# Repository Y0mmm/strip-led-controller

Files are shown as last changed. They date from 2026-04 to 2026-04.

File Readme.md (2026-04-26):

# STM8 RGB LED Strip Controller (Infrared NEC)

Custom low-cost RGB LED strip controller based on STM8, featuring Infrared (NEC protocol) control and perceptually-correct dimming.

## Overview

I bought a Paulmann SimpLED RGB strip to use as a bedside lamp. However, I was not satisfied with its functionalities (RGB light strobes before sleep didn’t make much sense), the colors were too aggressive for my eyes, and the dimming was linear (whereas human vision behaves more like a logarithmic response).

I initially wanted to reflash the original controller, but there were no markings on the IC package. So I decided to rebuild it from scratch.

This redesign addresses those issues with:
- Smooth, perceptually-correct brightness control
- Customizable color profiles
- Infrared remote compatibility (NEC protocol)
- Minimal, low-cost hardware

### Features

- Customizable color mapping
- Smooth, perceptually-correct brightness control
- Customizable color functions (ie: go-to-bed that slowly switch off the lights)
- Drop-in replacement PCB for original enclosure

## Hardware
### PCB Design
The PCB form factor and the position of the power barrel connector are designed to fit into the original controller enclosure and to be powered with the original 12VDC power supply.
I chose to use an STM8S001, as it is inexpensive, low-power, and more than sufficient for this project.

PCB design files are available in the PCB/ directory (KiCad).

### Preview
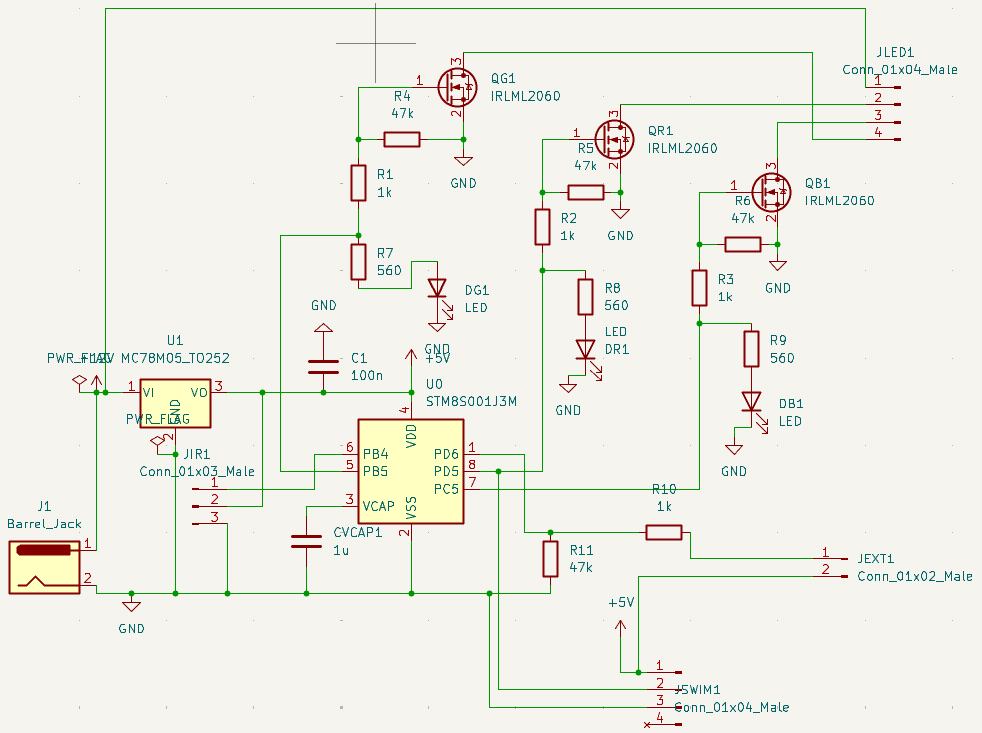
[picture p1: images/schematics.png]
wireing schematics


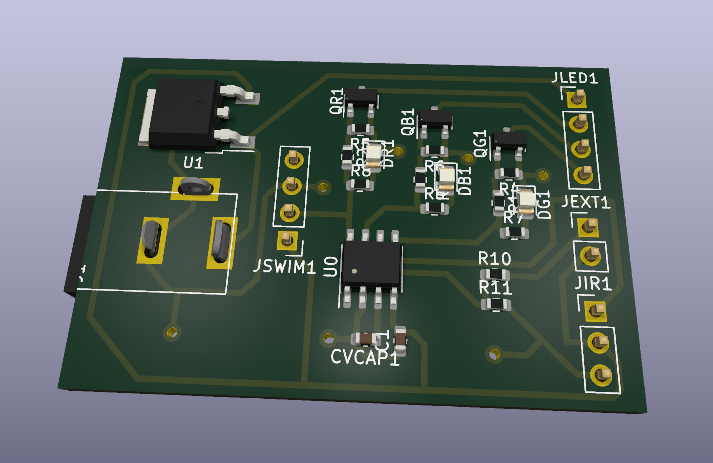
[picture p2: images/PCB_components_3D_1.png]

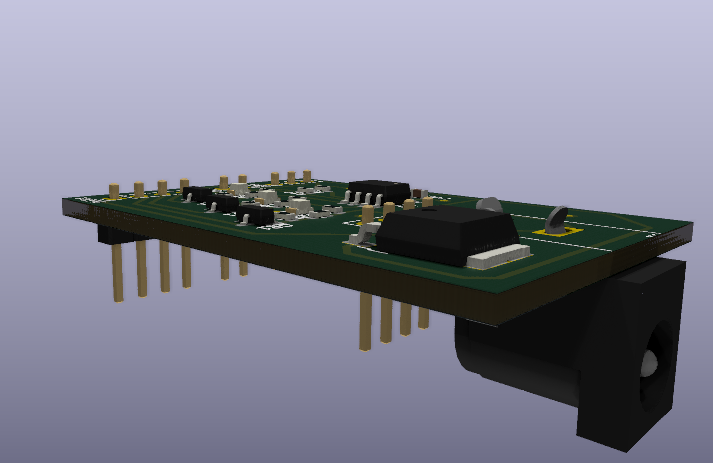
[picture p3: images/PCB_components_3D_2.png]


### Materials
|Name | Value | 	Number	| Comments|
| --- | ----- | --- | ---|
|STM8S001J3M3 |	|	1	|https://fr.farnell.com/stmicroelectronics/stm8s001j3m3/mcu-8bit-16mhz-nsoic-8/dp/4036166|
|MC78M05CDTRKG| | 		1|	7805 LDO regulator https://fr.farnell.com/on-semiconductor/mc78m05cdtrkg/regulateur-de-tension/dp/1703354|
|IRLML6344TRPBF	||	3	|N-channel MOSFETs used to control the LEDs https://fr.farnell.com/infineon/irlml6344trpbf/mosfet-canal-n-30v-6-3a-sot23/dp/1857299|
|MJ-179PH|	|	1|	Barrel power connector https://fr.farnell.com/multicomp-pro/mj-179ph/embase-basse-tension-12vdc-4a/dp/1737246|
|TSOP18438	|	|1|	IR receiver (replacement for the original one I broke — this one is actually more powerful) https://fr.farnell.com/vishay/tsop18438/recepteur-ir-24m-0-12mw-m2-lateral/dp/2889952|
|C1|	100 nF	|1|	1608 SMD|
|CVCAP	|1 µF	|1|	1608 SMD|
|R1, R2, R3	|1 kΩ|	3	|Load resistors for the MOSFETs, 1608 SMD|
|R4, R5, R6	|47 kΩ|	3	|Pull-down resistors, 1608 SMD|
|R7, R8, R9	|550 Ω|	3	|Optional load resistors for the LEDs, 1608 SMD|
|R10|	47 kΩ|	1	|Optional pull-down resistor for the JEXT button (not implemented)|
|R11|	1 kΩ	|1|	Load resistor for the optional JEXT button|
|RGB LEDs|	R, G, B|	3|	Optional, for debugging without the LED strip connected, 2012 SMD|
|Pin headers	|	|4	|Used for SWIM programming, IR receiver connection, and LED strip connection|

### IR remote buttons mapping : 
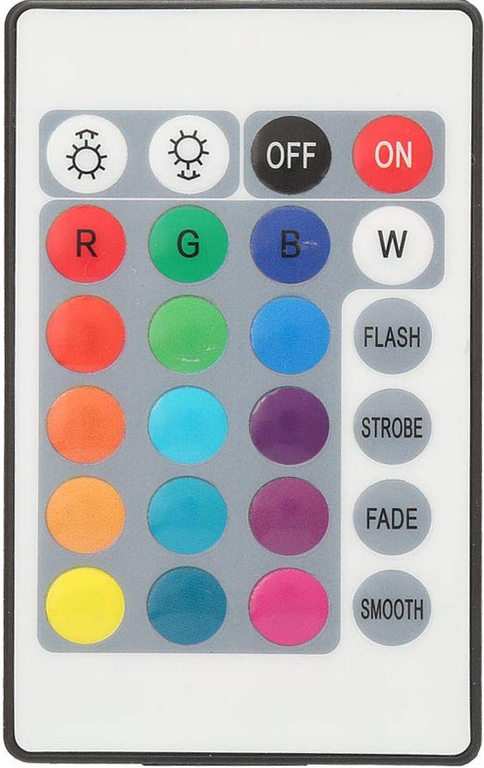
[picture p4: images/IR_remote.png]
IR Remote


For all the buttons, the NEC Address is `0xef00`. The commands are the following:
| Col A  | Col B  | Col C  | Col D  |
| --- | --- | --- | --- |
| `0x00` | `0x01` | `0x02` | `0x03` |
| `0x04` | `0x05` | `0x06` | `0x07` |
| `0x08` | `0x09` | `0x0a` | `0x0b` | 
| `0x0c` | `0x0d` | `0x0e` | `0x0f` | 
| `0x10` | `0x11` | `0x12` | `0x13` | 
| `0x14` | `0x15` | `0x16` | `0x17` | 

## Firmware
I wrote the NEC infrared decoder from scratch, mainly for fun. It is built around a finite state machine. The command handler is implemented as a large switch statement.

The firmware is interrupt-driven, aiming to minimize power consumption (although it is not battery-powered).

You can add your own colors in src/config/led_config.c, adjust command codes to match your remote control, and implement additional features.

Since the STM8S001 does not include an FPU, all arithmetic is done using fixed-point math.

I used OpenAI Codex at the end to help refactor parts of the code.

### TODO
Implement features using a button connected to JEXT (e.g., on/off)

### Compile
I use SDCC for compilation. 
usage :
`make clean && make`

flash: I used a stlinkv2 with a SWIM Connector
`make flash`

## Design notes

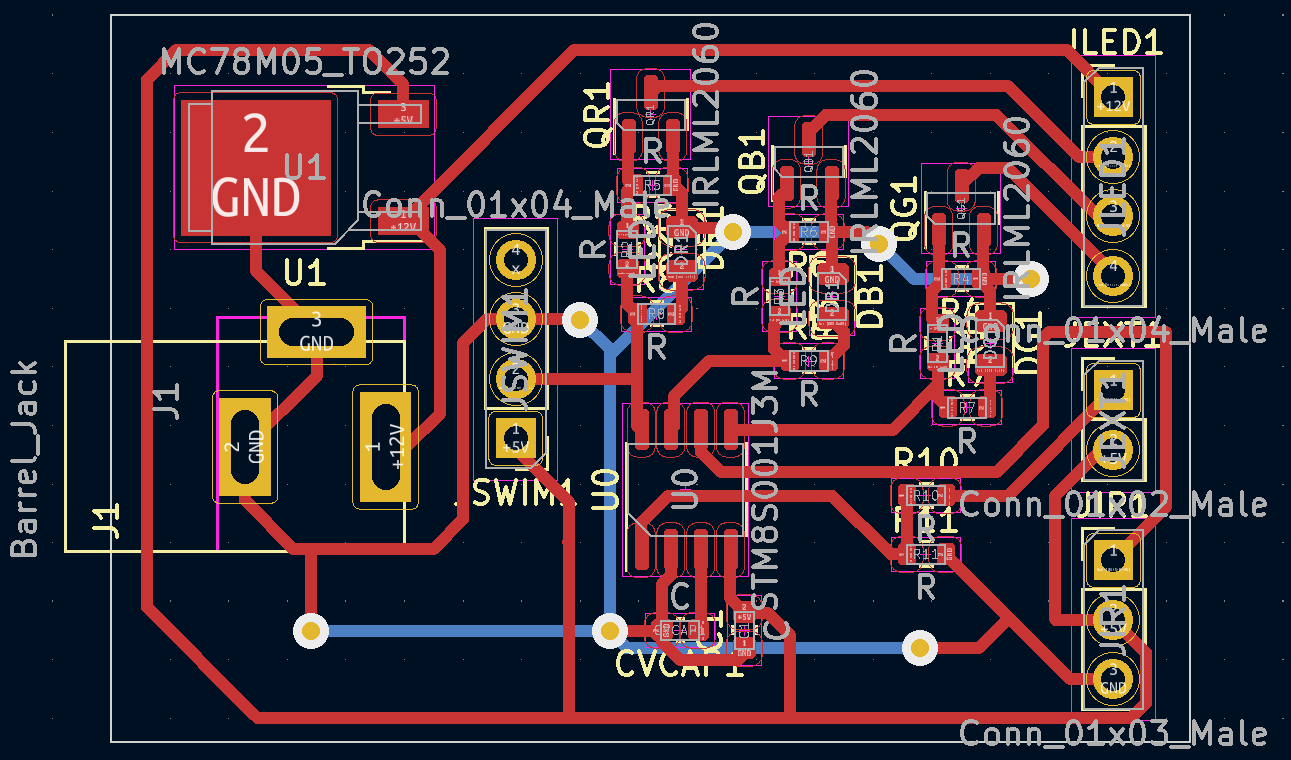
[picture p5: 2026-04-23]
images/PCB_schematics.png

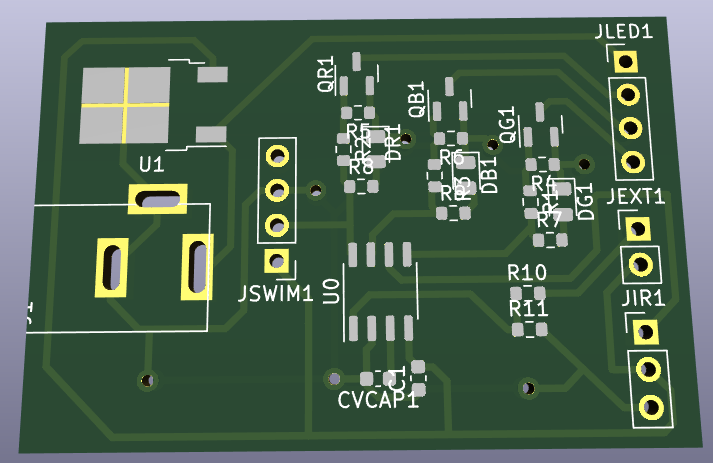
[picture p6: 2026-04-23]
images/PCB_3D.png

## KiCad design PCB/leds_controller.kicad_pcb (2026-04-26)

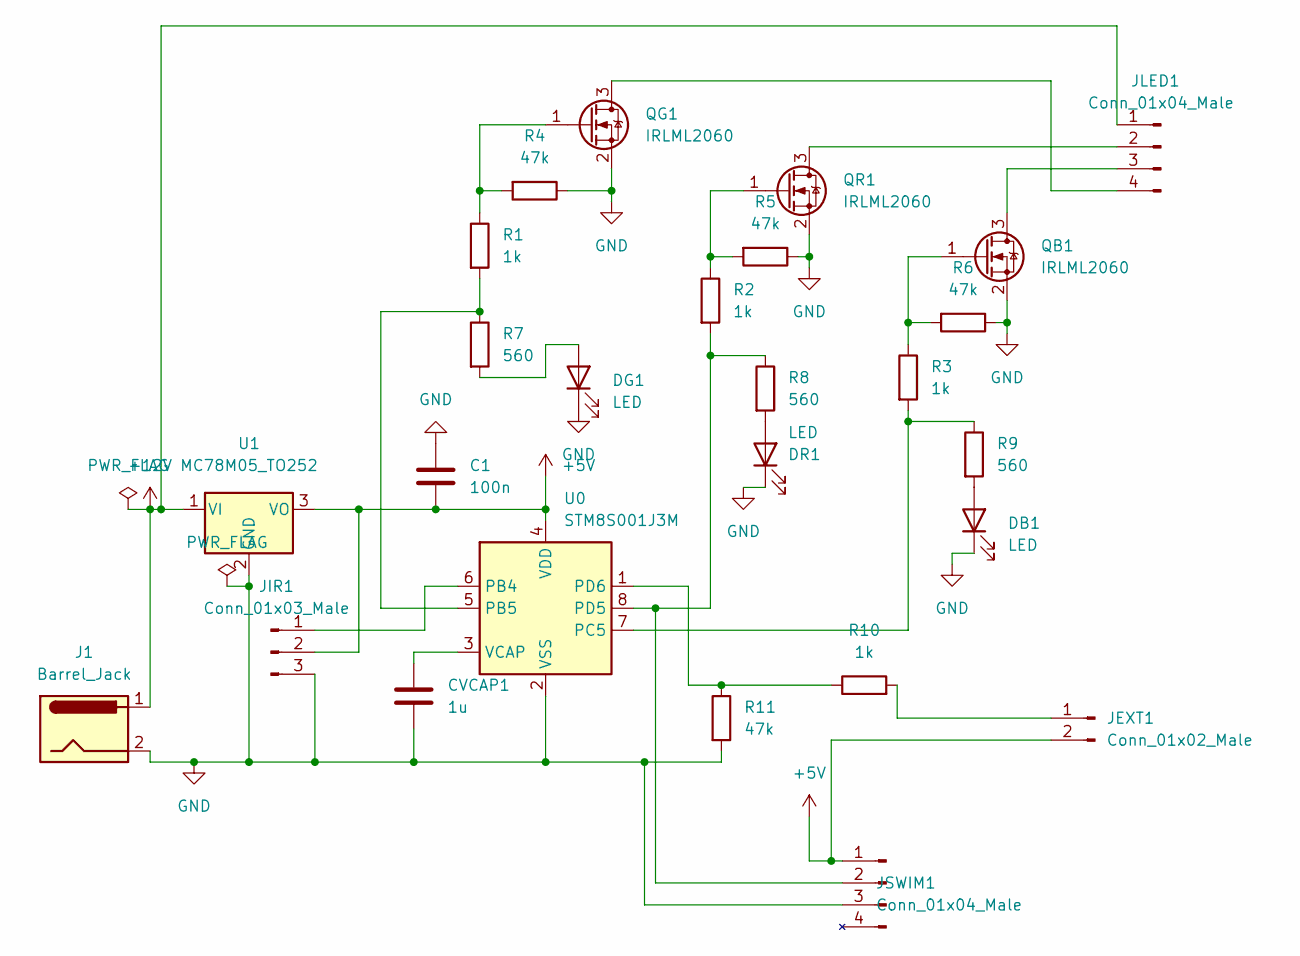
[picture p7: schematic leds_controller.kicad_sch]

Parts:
C1: 100n; C_0603_1608Metric
CVCAP1: 1u; C_0603_1608Metric
DB1: LED; LED_0805_2012Metric
DG1: LED; LED_0805_2012Metric
DR1: LED; LED_0805_2012Metric
J1: Barrel_Jack; BarrelJack_MJ-179PH
JEXT1: Conn_01x02_Male; PinHeader_1x02_P2.54mm_Vertical
JIR1: Conn_01x03_Male; PinHeader_1x03_P2.54mm_Vertical
JLED1: Conn_01x04_Male; PinHeader_1x04_P2.54mm_Vertical
JSWIM1: Conn_01x04_Male; PinHeader_1x04_P2.54mm_Vertical
QB1: IRLML2060; SOT-23
QG1: IRLML2060; SOT-23
QR1: IRLML2060; SOT-23
R1, R2, R3, R10: 1k; R_0603_1608Metric
R4, R5, R6, R11: 47k; R_0603_1608Metric
R7, R8, R9: 560; R_0603_1608Metric
U0: STM8S001J3M; SO-8_3.9x4.9mm_P1.27mm
U1: MC78M05_TO252; TO-252-2

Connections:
+5V: C1.2, JEXT1.2, JIR1.2, JSWIM1.1, U0.4 (VDD), U1.3 (VO)
+12V: J1.1, JLED1.1, U1.1 (VI)
GND: C1.1, CVCAP1.2, DB1.1 (K), DG1.1 (K), DR1.1 (K), J1.2, JIR1.3, JSWIM1.3, QB1.2 (S), QG1.2 (S), QR1.2 (S), R4.1, R5.1, R6.1, R11.2, U0.2 (VSS), U1.2 (GND)
unnamed: DB1.2 (A), R9.2
unnamed: DG1.2 (A), R7.2
unnamed: DR1.2 (A), R8.2
unnamed: JEXT1.1, R10.2
unnamed: JIR1.1, U0.6 (PB4)
unnamed: JLED1.2, QR1.3 (D)
unnamed: JLED1.3, QB1.3 (D)
unnamed: JLED1.4, QG1.3 (D)
unnamed: JSWIM1.2, R2.2, R8.1, U0.8 (PD5)
unnamed: QB1.1 (G), R3.1, R6.2
unnamed: QG1.1 (G), R1.1, R4.2
unnamed: QR1.1 (G), R2.1, R5.2
unnamed: R1.2, R7.1, U0.5 (PB5)
unnamed: R3.2, R9.1, U0.7 (PC5)
unnamed: R10.1, R11.1, U0.1 (PD6)
unnamed: CVCAP1.1, U0.3 (VCAP)

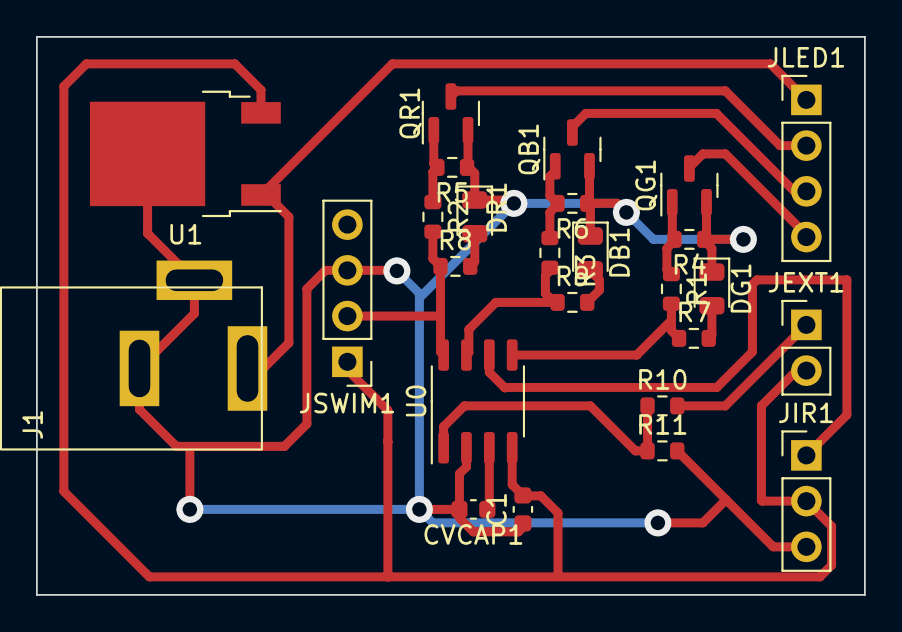
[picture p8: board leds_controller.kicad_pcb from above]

Board: 2 copper layers, 46.0 x 31.0 mm, 26 parts (0 on the bottom side), 19 nets.

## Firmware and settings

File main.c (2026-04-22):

#include <stdint.h>

#include "STM8S001J3.h"
#include "src/app/ir_commands.h"
#include "src/app/ir_decoder.h"
#include "src/app/led_features.h"
#include "src/app/led_state.h"
#include "src/config/led_config.h"
#include "src/drivers/peripherals.h"

static volatile IRDecoderState ir_decoder;
static LEDState leds_state = {
  LED_DEFAULT_IS_ON,
  LED_DEFAULT_DIM_LEVEL,
  LED_DEFAULT_HUE,
  LED_DEFAULT_SATURATION,
  LED_DEFAULT_VALUE,
  LED_DEFAULT_RED,
  LED_DEFAULT_GREEN,
  LED_DEFAULT_BLUE
};
static LEDTimerFeature led_timer_feature;

ISR_HANDLER(PORTB_ISR, _EXTI1_VECTOR_) {
  ir_decoder_on_edge(&ir_decoder);
}

ISR_HANDLER(TIM4_UPD_ISR, _TIM4_OVR_UIF_VECTOR_) {
  ir_decoder_on_timer_tick(&ir_decoder);
  sfr_TIM4.SR.UIF = 0;
}

ISR_HANDLER(TIM1_UPD_ISR, _TIM1_OVR_UIF_VECTOR_) {
  led_features_on_timer_tick(&led_timer_feature, &leds_state);
  sfr_TIM1.SR1.UIF = 0;
}

void main(void) {
  DISABLE_INTERRUPTS();

  /* Run the core at the full 16 MHz HSI rate so all timer calculations match hw_config.h. */
  sfr_CLK.CKDIVR.byte = 0x00;

  peripherals_wait_for_swim();
  peripherals_init_ports();
  peripherals_init_ir_timer();
  peripherals_init_gpio_interrupt();
  peripherals_init_leds_timer();
  peripherals_leds_pwm_set_frequency(LED_PWM_FREQUENCY_CENTI_HZ);
  peripherals_init_led_feature_timer();

  ir_decoder_init(&ir_decoder);
  led_features_init(&led_timer_feature);

  ENABLE_INTERRUPTS();

  peripherals_leds_start(&leds_state);
  peripherals_leds_stop();

  while (1) {
    IRDecoderStatus decoder_status;

    WAIT_FOR_INTERRUPT();
    decoder_status = ir_decoder_get_status(&ir_decoder);
    if (decoder_status == IR_DECODER_STATUS_NONE) {
      NOP();
      continue;
    }

    ir_decoder_clear_status(&ir_decoder);
    if (decoder_status == IR_DECODER_STATUS_FRAME) {
      ir_commands_handle(ir_decoder_get_command(&ir_decoder), &leds_state, &led_timer_feature);
    } else if (decoder_status == IR_DECODER_STATUS_REPEAT) {
      if (ir_decoder_get_repeat_counter(&ir_decoder) >= IR_REPEAT_ACTION_THRESHOLD) {
        ir_decoder_reset_repeat_counter(&ir_decoder);
        ir_commands_handle(ir_decoder_get_command(&ir_decoder), &leds_state, &led_timer_feature);
      }
    }

    NOP();
  }
}

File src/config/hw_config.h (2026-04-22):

#ifndef HW_CONFIG_H
#define HW_CONFIG_H

#include "../../STM8S001J3.h"

#define LED_DEBUG_PIN_NR 3
#define LED_DEBUG_PIN PIN3
#define LED_DEBUG_PORT sfr_PORTA

#define IR_PIN_NR 4
#define IR_PIN PIN4
#define IR_PORT sfr_PORTB

#define RED_PWM_CHAN 1
#define GREEN_PWM_CHAN 2
#define BLUE_PWM_CHAN 3

#define RED_PIN PIN3
#define RED_PORT sfr_PORTA

#define GREEN_PIN PIN5
#define GREEN_PORT sfr_PORTC

#define BLUE_PIN PIN3
#define BLUE_PORT sfr_PORTD

#define MCU_MASTER_CLOCK_HZ 16000000UL
#define SWIM_STARTUP_DELAY_LOOPS 2500000UL
#define LED_INTENSITY_SCALE_MAX 1000U
#define LED_PWM_TIMER_DEFAULT_PRESCALER 4U

/* TIM4 runs the IR decoder timebase at 100 us per tick: 16 MHz / 2^6 / (24 + 1) = 10 kHz. */
#define IR_TIMER_TICK_US 100U
#define IR_TIMER_PRESCALER 6U
#define IR_TIMER_ARR 24U

/* TIM1 overflows every 100 ms: 16 MHz / 16000 / 100 = 100 ms period. */
#define LED_FEATURE_TIMER_PSCRH 0x3e
#define LED_FEATURE_TIMER_PSCRL 0x7f
#define LED_FEATURE_TIMER_ARRH 0x00
#define LED_FEATURE_TIMER_ARRL 0x63

#endif

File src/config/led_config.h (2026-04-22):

#ifndef LED_CONFIG_H
#define LED_CONFIG_H

#include <stdint.h>

#define MAX_DIM_LEVEL 56
#define DIM_LEVELS_STEPS 3
#define LED_DEFAULT_IS_ON 0U
#define LED_DEFAULT_DIM_LEVEL 0
#define LED_DEFAULT_HUE 60U
#define LED_DEFAULT_SATURATION 1000U
#define LED_DEFAULT_VALUE 1000U
#define LED_DEFAULT_RED 1000U
#define LED_DEFAULT_GREEN 1000U
#define LED_DEFAULT_BLUE 1000U
#define LED_PWM_FREQUENCY_CENTI_HZ 10000UL
#define IR_REPEAT_ACTION_THRESHOLD 2U
/* 3000 ticks at 100 ms from TIM1 gives a 300 s fade-to-off. */
#define GO_TO_SLEEP_DURATION_TICKS 3000UL

#define COMMAND_ON 0x03
#define COMMAND_OFF 0x02
#define COMMAND_DIM_UP 0x00
#define COMMAND_DIM_DOWN 0x01
#define COMMAND_RED 0x04
#define COMMAND_GREEN 0x05
#define COMMAND_BLUE 0x06
#define COMMAND_WHITE 0x07
#define COMMAND_ORANGE 0x10
#define COMMAND_PINK_BARBIE 0x12
#define COMMAND_YELLOW 0x14
#define COMMAND_CYAN 0x15
#define COMMAND_PINK 0x16
#define COMMAND_GOTOSLEEP 0x17

#define RED_H 0U
#define RED_S 1000U
#define GREEN_H 120U
#define GREEN_S 1000U
#define BLUE_H 240U
#define BLUE_S 1000U
#define WHITE_H 0U
#define WHITE_S 0U
#define ORANGE_H 18U
#define ORANGE_S 1000U
#define YELLOW_H 24U
#define YELLOW_S 980U
#define PINK_H 350U
#define PINK_S 910U
#define PINK_BARBIE_H 352U
#define PINK_BARBIE_S 960U
#define CYAN_H 180U
#define CYAN_S 700U

extern const uint16_t led_log_abacus[MAX_DIM_LEVEL + 1];

#endif

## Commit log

2026-04-23 updating to kicad 10, including 3D models screenshots
    [leds_controller.kicad_pcb, leds_controller.kicad_sch]
2026-04-26 updated doc
    [leds_controller.kicad_pcb, leds_controller.kicad_sch]
